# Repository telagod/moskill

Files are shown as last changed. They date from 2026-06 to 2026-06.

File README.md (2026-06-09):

<p align="center">
  MosKill Logo
</p>

<h1 align="center">MosKill</h1>
<p align="center">
  <strong>Smart Mosquito Swatter with BLE, Kill Counting & Statistics</strong><br/>
  <em>ESP32-C3 Firmware + KiCad PCB + UniApp Cross-Platform Client</em>
</p>

<p align="center">
  
  
  
  
  
  
  
</p>

---

## System Architecture

<p align="center">
  System Architecture
</p>

## Features

- **Kill Detection** — Current pulse analysis, 4-class classification (S Fruit Fly / M Mosquito / L House Fly / XL Moth)
- **Statistics Engine** — Total kills, streak records, hourly heatmap, size distribution, efficiency scoring
- **Environment Correlation** — AHT20 temp/humidity sensing, mosquito activity vs. environment cross-analysis
- **BLE 5.0** — Real-time kill notifications, stats read, device config, OTA firmware update
- **UI Feedback** — WS2812B color-coded kill effects, streak rainbow animation, buzzer sound FX
- **Power Management** — 18650 Li-ion USB-C charging, 5-min auto deep sleep (5uA)
- **Cross-Platform App** — WeChat Mini Program / Android / iOS / H5, i18n (zh/en), dev mode
- **Fully AI-Designed** — From empty directory to manufacturable Gerber, zero human intervention

## PCB Design

30 x 100 mm narrow strip designed to fit inside a mosquito swatter handle. 91 components, dual-layer with full GND pour.

<p align="center">
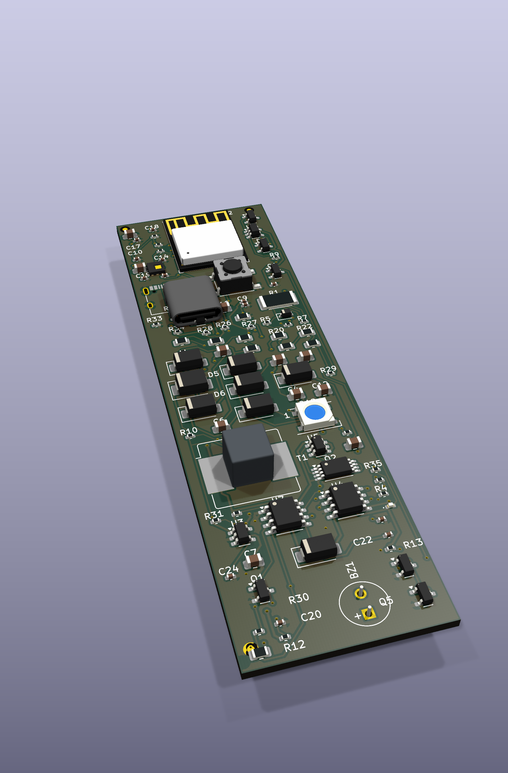
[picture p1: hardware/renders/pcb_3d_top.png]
PCB 3D Top
  
  &nbsp;&nbsp;&nbsp;&nbsp;
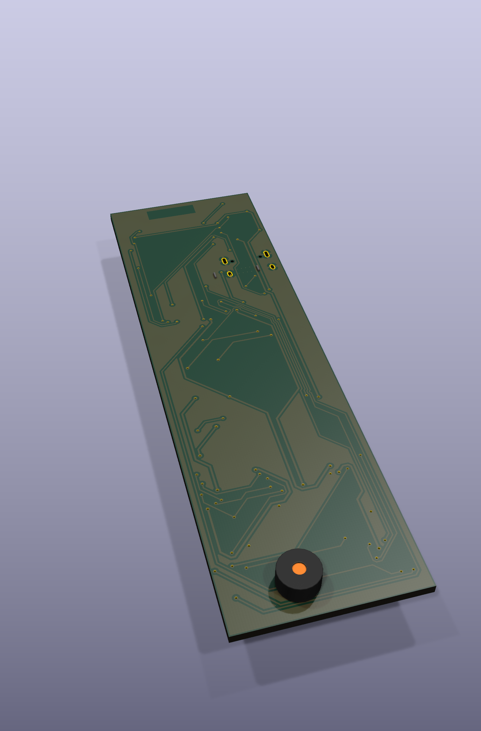
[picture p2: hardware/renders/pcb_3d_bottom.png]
PCB 3D Bottom
  
  &nbsp;&nbsp;&nbsp;&nbsp;
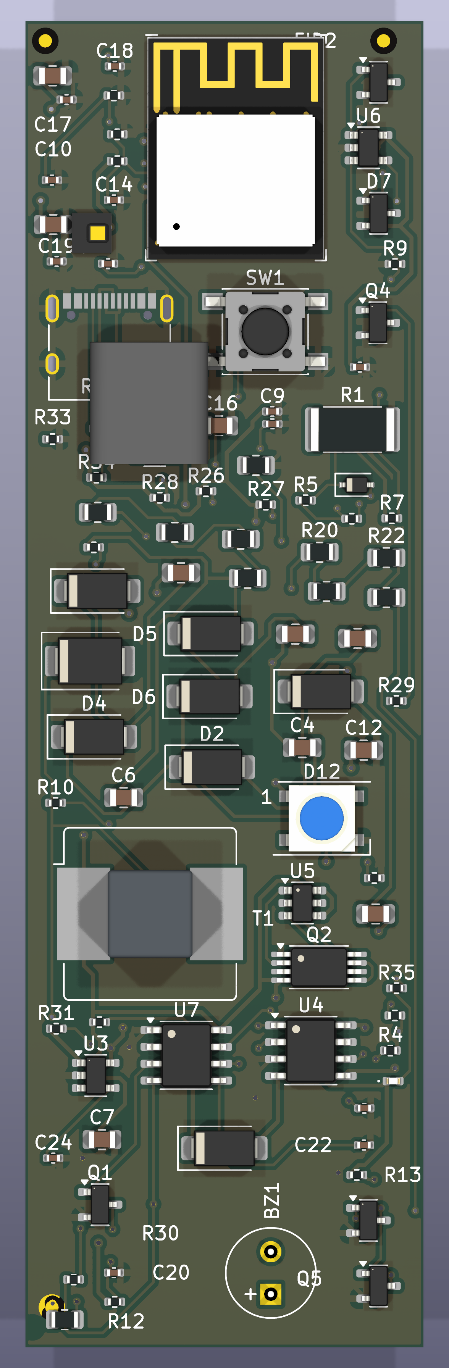
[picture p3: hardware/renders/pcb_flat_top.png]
PCB Flat Top
  
  &nbsp;&nbsp;&nbsp;&nbsp;
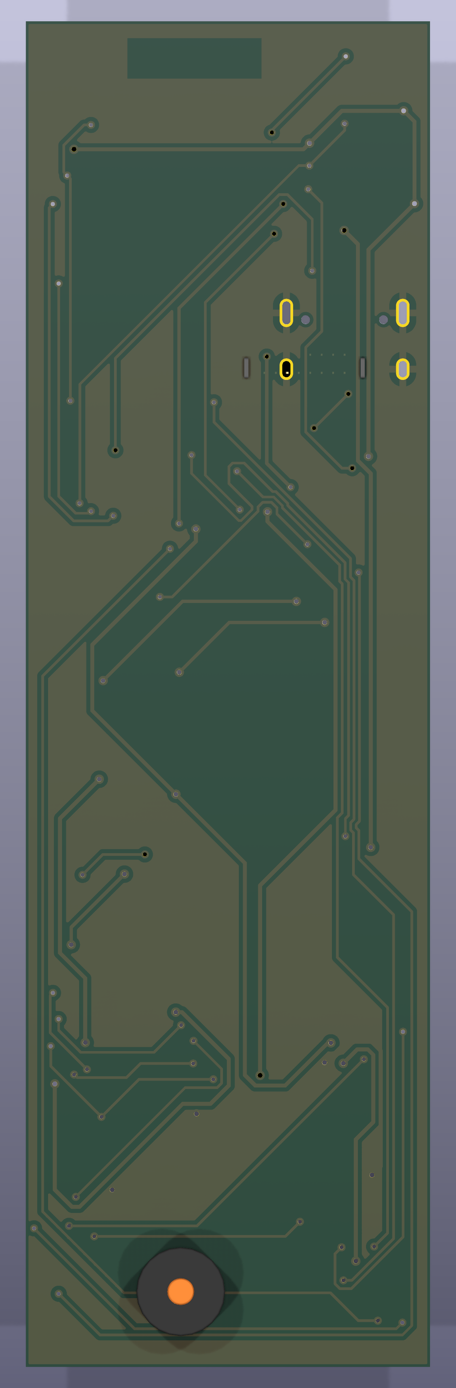
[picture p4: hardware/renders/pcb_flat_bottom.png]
PCB Flat Bottom
  
</p>
<p align="center"><em>Left to right: 3D Top, 3D Bottom, Flat Top, Flat Bottom</em></p>

## Hardware

| Component | Part | Function |
|---|---|---|
| MCU | ESP32-C3-MINI-1 | RISC-V 160MHz, BLE 5.0, 4MB Flash |
| HV Boost | NE555 + AO3400 + EE13 Transformer (10:200) | 3.7V -> ~2000V DC |
| HV Multiplier | 3-stage Cockcroft-Walton (UF4007 + 1nF/2kV) | Voltage tripler |
| Current Sense | 0.1ohm + LMV358 (Gain=20) + BAT43 Peak Det | Kill waveform capture |
| Env Sensor | AHT20 (I2C) | Temp +/-0.3C / Humidity +/-2%RH |
| Power | 18650 + TP4056 + ME6211 LDO | USB-C charging, 3.3V regulated |
| Battery Protect | DW01A + FS8205A | Over-charge/discharge/current protection |
| LED | WS2812B | RGB status + kill effects |
| Buzzer | KCG0601 Passive Piezo | Kill sound FX + streak rising tone |

> Full schematic: [`hardware/kicad/moskill.kicad_sch`](hardware/kicad/moskill.kicad_sch) | BOM: [`hardware/bom/BOM.csv`](hardware/bom/BOM.csv) | Gerber: [`hardware/kicad/moskill-gerbers.zip`](hardware/kicad/moskill-gerbers.zip)

## Project Structure

```
moskill/
├── firmware/                        # ESP-IDF v5.4 firmware (938KB binary)
│   ├── main/                        # Entry point, 6 FreeRTOS tasks
│   └── components/
│       ├── kill_detector/           # 4-state kill detection FSM
│       ├── stats_engine/            # Statistics + NVS sharded storage
│       ├── ble_service/             # BLE GATT server + OTA handler
│       ├── env_sensor/              # AHT20 I2C driver (thread-safe)
│       ├── power_mgmt/             # Battery curve, HV control, deep sleep
│       └── hv_driver/              # WS2812B RMT driver
├── hardware/
│   ├── kicad/                       # KiCad 9 schematic + PCB (30x100mm)
│   ├── bom/BOM.csv                  # 48 line items, ~¥24.48
│   └── renders/                     # 3D and flat PCB renders
├── app/                             # UniApp cross-platform client
│   └── src/
│       ├── pages/                   # 7 pages (dashboard, stats, rank, control, ota, ...)
│       ├── components/MkIcon.vue    # SVG icon component (38 icons)
│       ├── utils/
│       │   ├── ble.js               # BLE communication layer (128-bit UUIDs)
│       │   ├── icons.js             # SVG icon definitions
│       │   ├── i18n.js              # Chinese/English auto-switch
│       │   └── mock.js              # Dev mode mock data generator
│       └── store/index.js           # Vuex state management
├── protocol/ble_protocol.md         # BLE GATT protocol specification
├── tools/ble_debug/                 # Python BLE debug tool (bleak + rich)
└── docs/DESIGN.md                   # Full system design document
```

## Build Firmware

```bash
# Install ESP-IDF v5.4+
# https://docs.espressif.com/projects/esp-idf/en/latest/esp32c3/get-started/

cd firmware
idf.py set-target esp32c3
idf.py build                         # -> build/moskill.bin (938KB)
idf.py -p /dev/ttyUSB0 flash monitor
```

## Build App

```bash
cd app
npm install
npx uni build                        # H5 build
npx uni build -p mp-weixin           # WeChat Mini Program
npx uni dev:h5                       # H5 dev server

# Dev mode: no device needed, uses mock data for UI development
```

## Kill Detection Pipeline

```
ADC 1kHz sampling -> Threshold trigger -> Sustain check (>=5ms)
    -> Peak capture -> Envelope match -> Classification -> Stats update
    -> BLE notify -> LED + Buzzer feedback

Classification by peak ADC:
  S  (< 800)    Fruit Fly
  M  (800-2000) Mosquito
  L  (2000-3200) House Fly
  XL (> 3200)   Moth / Beetle
```

## BLE Protocol

128-bit custom UUIDs (base `e3a1XXXX-f5e8-4c8a-9b3d-2c1f7b8a6d50`), packed wire format for efficiency.

| Service | UUID Short | Description |
|---|---|---|
| MosKill Main | `0x1B00` | Kill count (notify), session/lifetime stats, kill log, environment |
| Config | `0x1B11` | Sensitivity, LED, buzzer, streak effects + time sync |
| OTA | `0x1B21` | Firmware update (start/write/verify/abort with CRC32) |
| Battery | `0x180F` | Standard Battery Service |

> Full protocol spec: [`protocol/ble_protocol.md`](protocol/ble_protocol.md)

## BLE Debug Tool

```bash
cd tools/ble_debug
pip install -r requirements.txt

python moskill_ble.py scan                          # Scan devices
python moskill_ble.py stats <ADDR>                  # Read statistics
python moskill_ble.py monitor <ADDR>                # Real-time kill monitor
python moskill_ble.py config <ADDR> -s 2 -b 3      # Set sensitivity/buzzer
python moskill_ble.py ota <ADDR> firmware.bin       # BLE OTA update
```

## License

MIT

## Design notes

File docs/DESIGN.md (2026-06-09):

# MosKill - Smart Electric Mosquito Swatter

## System Overview

ESP32-C3 based smart mosquito swatter with BLE connectivity, real-time kill detection via current pulse analysis, and comprehensive kill statistics including waveform classification, environmental correlation, and efficiency scoring.

```
┌─────────────────────────────────────────────────────┐
│                   MosKill System                    │
│                                                     │
│  ┌──────────┐   ┌──────────┐   ┌───────────────┐   │
│  │ HV Grid  │──▶│ Current  │──▶│   ESP32-C3    │   │
│  │ 3-layer  │   │ Sensing  │   │               │   │
│  └──────────┘   └──────────┘   │  ┌─────────┐  │   │
│                                │  │Kill Det. │  │   │
│  ┌──────────┐                  │  ├─────────┤  │   │
│  │ Boost    │◀─────────────────│  │Stats Eng│  │   │
│  │ Converter│   Control        │  ├─────────┤  │   │
│  └──────────┘                  │  │BLE Stack│  │   │
│                                │  ├─────────┤  │   │
│  ┌──────────┐                  │  │Power Mgr│  │   │
│  │ AHT20    │─────────────────▶│  ├─────────┤  │   │
│  │Temp/Humi │   I2C            │  │Env Sense│  │   │
│  └──────────┘                  │  └─────────┘  │   │
│                                └───────────────┘   │
│  ┌──────────┐   ┌──────────┐                       │
│  │ Li-ion   │──▶│ LDO 3.3V │──▶ System Power       │
│  │ 18650    │   │ ME6211   │                       │
│  └──────────┘   └──────────┘                       │
└─────────────────────────────────────────────────────┘
```

## 1. Hardware Architecture

### 1.1 MCU - ESP32-C3-MINI-1

| Parameter | Value |
|---|---|
| Core | RISC-V 32-bit, 160MHz |
| Flash | 4MB |
| SRAM | 400KB |
| BLE | 5.0 |
| ADC | 12-bit SAR, 6 channels |
| GPIO | 22 pins |
| Deep Sleep | 5μA |
| Package | ESP32-C3-MINI-1 module |

#### Pin Assignment

| Pin | Function | Description |
|-----|---|---|
| GPIO0 | ADC_CH0 | Current sense input (via analog frontend) |
| GPIO1 | ADC_CH1 | Battery voltage divider |
| GPIO2 | BOOT | Boot mode (active low) |
| GPIO3 | ADC_CH3 | Env sensor aux (optional) |
| GPIO4 | I2C_SDA | AHT20 data |
| GPIO5 | I2C_SCL | AHT20 clock |
| GPIO6 | HV_EN | High voltage boost enable |
| GPIO7 | LED_STATUS | Status LED (RGB WS2812B) |
| GPIO8 | BUZZER | Piezo buzzer PWM |
| GPIO9 | BUTTON | Main button (active low, internal pull-up) |
| GPIO10 | CHG_STAT | TP4056 charge status |
| GPIO18 | USB_D- | USB-C data |
| GPIO19 | USB_D+ | USB-C data |
| GPIO20 | UART_RX | Debug UART |
| GPIO21 | UART_TX | Debug UART |

### 1.2 High Voltage System

#### Boost Converter (Battery → HV)

```
Li-ion 3.7V ──▶ Oscillator + Transformer ──▶ Voltage Multiplier ──▶ ~2000V DC
                     │                              │
                  GPIO6 EN                    Current Sense
                                                    │
                                              To Analog Frontend
```

**Oscillator**: NE555 astable driving MOSFET gate
- R_A = 4.7kΩ, R_B = 10kΩ, C_t = 10nF
- f = 1.44 / ((R_A + 2×R_B) × C_t) = 1.44 / ((4.7k + 2×10k) × 10nF) = **5.83kHz**
- Duty cycle = (R_A + R_B) / (R_A + 2×R_B) = 14.7k / 24.7k = **59.5%**

**MOSFET**: AO3400 (N-ch, Vds=30V, Rds_on=40mΩ, Id=5.7A, SOT-23)
- RC snubber across drain-source: **100Ω + 1nF** (suppresses ringing)
- TVS across drain-source: **SMBJ24A** (24V standoff, 38.9V clamp, flyback protection)

**Transformer**: EE13 or EE16 core, **10:200 winding ratio (1:20 effective)**
- 10 primary turns: inductance ~200μH
- Peak primary current: I = V × t_on / L = 3.7V × 100μs / 200μH = **1.85A** (safe for AO3400)
- 200 secondary turns: V_sec_peak = V_in × N_s/N_p = 3.7 × 20 = **~740V peak** at 3.7V input

**Voltage Multiplier**: Cockcroft-Walton 3-stage
- C: 1nF 2kV rated (C0G dielectric)
- D: **UF4007** (fast recovery, trr=75ns, 1kV, 1A) — standard 1N4007 too slow for 5.8kHz switching
- No-load output: 6 × 740V = 4440V theoretical × 0.7 efficiency ≈ **3100V**
- Loaded output (grid + insect): **~2000V DC** target achieved
- Design margin: Vout adjustable via duty cycle / frequency trim

**Grid**: 3-layer structure
- Outer layers: Ground reference
- Inner layer: High voltage
- Spacing: 3-4mm

#### Current Sensing Analog Frontend

```
HV Return ──┤R_sense├──▶ GND
                │
                ▼
         ┌──────────────┐
         │  R_sense      │  0.1Ω 2W (gives 100mV at 1A, manageable range)
         │  voltage drop │
         └──────┬───────┘
                │
         ┌──────▼───────┐
         │ Series Limit  │  1kΩ resistor BEFORE clamp (limits inrush to clamp diodes)
         │ Resistor      │
         └──────┬───────┘
                │
         ┌──────▼───────┐
         │ Clamping      │  BAT54S Schottky clamp to 0-3.3V
         │ Protection    │
         └──────┬───────┘
                │
         ┌──────▼───────┐
         │ Backup Zener  │  BZX84C3V3 (3.3V Zener, SOT-23) — secondary hard clamp
         └──────┬───────┘
                │
         ┌──────▼───────┐
         │ Op-Amp Stage  │  LMV358 (rail-to-rail, 3.3V)
         │ Gain = 20     │  Non-inverting: Rf=19kΩ, Rg=1kΩ
         │ BW filter     │  RC LPF at 10kHz (anti-alias)
         └──────┬───────┘
                │
         ┌──────▼───────┐
         │ Peak Detector │  BAT43 Schottky (Vf≈0.2V, preserves small signals)
         │ + Envelope    │  + RC hold: 1μF × 100kΩ = τ = 100ms
         └──────┬───────┘
                │
                ▼
           GPIO0 (ADC)     12-bit, sampled at 1kHz during active mode
```

**Design Notes:**
- R_sense = 0.1Ω 2W: produces 10-100mV at typical kill currents (100mA-1A peak)
- 1kΩ series resistor before BAT54S clamp limits fault current into protection diodes
- BZX84C3V3 Zener backup provides hard 3.3V clamp if Schottky clamp fails
- LMV358 gain of 20x (Rf=19kΩ, Rg=1kΩ) maps 0-165mV to 0-3.3V, linear up to 1.65A
- RC filter (R=1.5kΩ, C=10nF → fc ≈ 10.6kHz) for anti-aliasing
- Peak detector uses BAT43 Schottky (low Vf ≈ 0.2V) to preserve small signals
- Peak detector with 1μF + 100kΩ gives τ = 100ms — fast enough for consecutive kills

### 1.3 Power System

#### Battery
- Cell: 18650 Li-ion, 2600mAh
- Nominal: 3.7V (range 3.0V-4.2V)
- Protection: DW01A + FS8205A (overcurrent, overdischarge, overcharge)

#### Charging
- IC: TP4056 with DW01A
- Input: USB-C (5V) with **SS34 Schottky** in series for VBUS reverse protection
- USB ESD protection: **USBLC6-2SC6** on D+/D- lines
- Input capacitor: **4.7μF** (per TP4056 datasheet, 100nF insufficient for USB cable inductance)
- TEMP pin: connected through **10kΩ to VCC** (NOT to GND — GND disables charging)
- Charge current: 500mA (R_prog = 2kΩ)
- Status: CHRG pin → GPIO10

#### LDO Regulator
- IC: ME6211C33 (3.3V, 500mA, low Iq)
- Decoupling: 10μF + 100nF at output
- Enable: Always on (tied to battery via switch)

#### Battery Monitoring
- Voltage divider: **10kΩ / 10kΩ** → GPIO1 (ADC), with **100nF** filter cap at midpoint
  - Lower impedance reduces ADC noise and leakage current errors
  - Quiescent draw: ~0.2mA (acceptable vs. 100kΩ divider's noise issues)
- Reading: V_bat = ADC_reading × 2 × 3.3 / 4095
- Calibrated curve for SoC estimation

### 1.4 Environmental Sensor

- IC: AHT20 (I2C, 0x38)
- Temperature: -40°C to +85°C, ±0.3°C
- Humidity: 0-100% RH, ±2%
- Power: 2.2-5.5V, typ 23μA
- Sample rate: Every 30 seconds (low duty)

### 1.5 User Interface

#### Status LED (WS2812B)
| State | Color | Pattern |
|---|---|---|
| Idle | Off | - |
| Armed (HV on) | Red | Steady |
| Kill detected | Green | Flash 200ms |
| Multi-kill streak | Rainbow | Chase 500ms |
| BLE connected | Blue | Breathe |
| Charging | Orange | Pulse |
| Low battery | Red | Blink slow |

#### Buzzer (Passive piezo)
- Kill confirm: 2kHz, 50ms
- Streak (3+): Rising tone
- Low battery: 1kHz, 3× beep
- BLE connect: 2-tone chime

#### Button
- Short press: Toggle HV on/off
- Long press (3s): BLE advertising toggle
- Double press: Read stats via buzzer pattern

### 1.6 PCB Specifications

| Parameter | Value |
|---|---|
| Dimensions | 35mm × 60mm (fits in swatter handle) |
| Layers | 2 |
| Copper | 1oz outer |
| Finish | HASL lead-free |
| Min trace | 0.2mm (8mil) |
| Min drill | 0.3mm |
| HV clearance | ≥ 4mm between HV traces and LV |
| Substrate | FR-4 1.6mm |

**Layout Zones:**
```
┌─────────────────────────────┐
│  USB-C    │   ESP32-C3      │
│  TP4056   │   Module        │
│  Charging │                 │
├───────────┤   BLE Antenna   │
│  Battery  │   Keep-out      │
│  Mgmt     │   Zone          │
├───────────┼─────────────────┤
│  Analog Frontend            │
│  (Ground guarded)           │
├─────────────────────────────┤
│  HV Section                 │
│  (Isolated, 4mm clearance)  │
│  NE555 + MOSFET + Xformer   │
│  Voltage Multiplier         │
│  Routing slots between zones│
│  Conformal coating required │
└─────────────────────────────┘
```

## 2. Firmware Architecture

### 2.1 RTOS Task Structure (ESP-IDF / FreeRTOS)

```
┌─────────────────────────────────────────────┐
│              FreeRTOS Tasks                  │
│                                              │
│  ┌────────────┐  Priority: 5 (Highest)       │
│  │ kill_detect │  Core 0, 4KB stack           │
│  │ _task       │  1kHz ADC sampling           │
│  └─────┬──────┘  → kill event queue           │
│        │                                      │
│  ┌─────▼──────┐  Priority: 4                  │
│  │ stats_task  │  Core 0, 8KB stack            │
│  │             │  Process kill events          │
│  └─────┬──────┘  → update stats, flash write  │
│        │                                      │
│  ┌─────▼──────┐  Priority: 3                  │
│  │ ble_task    │  Core 0, 6KB stack            │
│  │             │  GATT server, notifications   │
│  └────────────┘                               │
│                                               │
│  ┌────────────┐  Priority: 2                  │
│  │ env_task    │  Core 0, 2KB stack            │
│  │             │  AHT20 polling every 30s      │
│  └────────────┘                               │
│                                               │
│  ┌────────────┐  Priority: 1                  │
│  │ ui_task     │  Core 0, 2KB stack            │
│  │             │  LED + buzzer + button        │
│  └────────────┘                               │
│                                               │
│  ┌────────────┐  Priority: 0 (Lowest)         │
│  │ power_task  │  Core 0, 2KB stack            │
│  │             │  Battery monitoring, sleep    │
│  └────────────┘                               │
└─────────────────────────────────────────────┘
```

### 2.2 Kill Detection Algorithm

```
State Machine:
                    ┌──────────┐
            ┌──────▶│  IDLE    │◀─────────────┐
            │       └────┬─────┘              │
            │            │ ADC > threshold_low │
            │            ▼                     │
            │       ┌──────────┐              │
            │       │ TRIGGERED│              │
            │       └────┬─────┘              │
            │            │ sustain > 5ms       │
            │            ▼                     │
            │       ┌──────────┐   timeout    │
            │       │CONFIRMING├──────────────┘
            │       └────┬─────┘
            │            │ peak captured +
            │            │ envelope matches
            │            ▼
            │       ┌──────────┐
            └───────┤KILL_EVENT│
                    │ → queue  │
                    └──────────┘

Parameters:
- threshold_low:  200 (ADC counts, ~160mV → ~16mV at sense resistor)
- threshold_high: 3800 (ADC counts, clipping protection)
- min_sustain:    5ms (debounce, reject static/EMI)
- max_duration:   500ms (reject continuous shorts)
- cooldown:       200ms (between consecutive kills)
- envelope_match: rise < 2ms, hold 5-50ms, decay < 100ms
```

### 2.3 Kill Classification

Based on discharge waveform characteristics:

| Class | Peak ADC | Duration | Energy Proxy | Likely Target |
|---|---|---|--- |---|
| S (Small) | 200-800 | 5-15ms | Low | Fruit fly, gnat |
| M (Medium) | 800-2000 | 10-30ms | Medium | Mosquito |
| L (Large) | 2000-3200 | 20-80ms | High | House fly, moth |
| XL (Extra) | 3200+ | 50-200ms | Very High | Large moth, beetle |

Energy proxy = Σ(ADC_sample²) over event duration (proportional to I²t)

### 2.4 Statistics Engine

#### Data Structures (NVS Storage)

```c
// Per-session stats (RAM, flushed to NVS on session end)
typedef struct {
    uint32_t session_id;
    uint32_t start_time;        // epoch seconds
    uint32_t duration_sec;
    uint16_t kills_total;
    uint16_t kills_by_class[4]; // S, M, L, XL
    uint16_t max_streak;
    uint16_t current_streak;
    float    avg_temp;
    float    avg_humidity;
    uint32_t energy_total;      // Σ energy proxy
    uint16_t hv_on_time_sec;
    uint16_t swings_estimated;  // from accelerometer-free proxy (HV on/off cycles)
} session_stats_t;

// Lifetime aggregates (NVS, updated on session end)
typedef struct {
    uint32_t total_kills;
    uint32_t kills_by_class[4];
    uint32_t total_sessions;
    uint32_t total_active_sec;
    uint32_t best_streak;
    uint32_t best_session_kills;
    float    kill_rate_per_hour; // rolling average
    uint8_t  hourly_histogram[24];  // kills per hour-of-day
    uint8_t  daily_histogram[7];    // kills per day-of-week
} lifetime_stats_t;

// Kill event log (circular buffer in NVS, last 256 kills)
typedef struct {
    uint32_t timestamp;
    uint8_t  kill_class;        // S=0, M=1, L=2, XL=3
    uint16_t peak_adc;
    uint16_t duration_ms;
    uint32_t energy_proxy;
    int8_t   temperature;       // °C, rounded
    uint8_t  humidity;          // %RH, rounded
} kill_event_t;
```

#### Derived Metrics (computed on read, not stored)

- **Kill Rate**: kills / HV-on-hours
- **Efficiency Score**: kills / (HV-on-time × energy) — higher = more efficient swatter
- **Peak Hour**: hour-of-day with most kills historically
- **Mosquito Pressure Index**: kills/hour normalized by temp/humidity (higher temp+humidity = more mosquitoes expected, so fewer kills ≠ fewer mosquitoes)
- **Streak Record**: longest consecutive kills within 10s window
- **Size Distribution**: pie chart data of S/M/L/XL

## 3. BLE Protocol

See [protocol/ble_protocol.md](../protocol/ble_protocol.md) for full specification.

### GATT Service Summary

| Service | UUID | Description |
|---|---|---|
| MosKill Service | `0x1B00` | Primary service |
| Kill Count | `0x1B01` | Total kills (notify on change) |
| Session Stats | `0x1B02` | Current session (read) |
| Lifetime Stats | `0x1B03` | All-time stats (read) |
| Kill Log | `0x1B04` | Recent kills (read, paginated) |
| Environment | `0x1B05` | Temp + humidity (notify) |
| Battery | `0x180F` | Standard BAS |
| Device Info | `0x180A` | Standard DIS |
| Config | `0x1B10` | Sensitivity, LED, buzzer settings |
| Time Sync | `0x1B11` | Set RTC from phone |
| OTA | `0x1B20` | Firmware update |

## 4. Bill of Materials (Key Components)

| # | Component | Part | Qty | Est. Cost (¥) |
|---|---|---|-----|---|
| 1 | MCU Module | ESP32-C3-MINI-1 | 1 | 9.00 |
| 2 | Temp/Humidity | AHT20 | 1 | 2.50 |
| 3 | LDO | ME6211C33M5G | 1 | 0.30 |
| 4 | Charge IC | TP4056 | 1 | 0.40 |
| 5 | Battery Protect | DW01A + FS8205A | 1+1 | 0.50 |
| 6 | Op-Amp | LMV358 | 1 | 0.80 |
| 7 | HV MOSFET | AO3400 (N-ch, 30V, 40mΩ) | 1 | 0.35 |
| 8 | Timer | NE555 | 1 | 0.30 |
| 9 | HV Transformer | EE13/EE16 10:200 | 1 | 2.00 |
| 10 | HV Diodes | UF4007 (fast recovery) | 6 | 0.60 |
| 11 | HV Caps | 1nF 2kV | 6 | 0.60 |
| 12 | Sense Resistor | 0.1Ω 2W | 1 | 0.15 |
| 13 | Clamp Diode | BAT54S | 1 | 0.20 |
| 14 | Peak Det. Diode | BAT43 (Schottky) | 1 | 0.15 |
| 15 | Backup Zener | BZX84C3V3 | 1 | 0.10 |
| 16 | TVS Diode | SMBJ24A | 1 | 0.50 |
| 17 | RGB LED | WS2812B | 1 | 0.30 |
| 18 | Buzzer | Passive piezo | 1 | 0.50 |
| 19 | USB-C Connector | 16-pin | 1 | 0.50 |
| 20 | USB Reverse Prot. | SS34 Schottky | 1 | 0.30 |
| 21 | USB ESD Prot. | USBLC6-2SC6 | 1 | 0.50 |
| 22 | Discharge MOSFET | 2N7002 (N-ch) | 1 | 0.10 |
| 23 | Button | 6×6mm tactile | 1 | 0.10 |
| 24 | HV Bleed Resistors | 1MΩ 0805 200V | 10 | 0.20 |
| 25 | Snubber R | 100Ω 0402 | 1 | 0.01 |
| 26 | Snubber C | 1nF 0402 | 1 | 0.01 |
| 27 | Discharge R | 100Ω 0805 | 1 | 0.01 |
| 28 | Passives | R, C assorted | ~30 | 1.00 |
| 29 | PCB | 2-layer 35×60mm | 1 | 3.00 |
| | **Total** | | | **~¥24.48** |

(Battery 18650 and grid/handle not included — mechanical parts)

## 5. Safety Considerations

- HV section isolated with **4mm clearance** on PCB
- **PCB routing slots** between HV and LV zones to increase creepage distance
- **Conformal coating** required on HV section (silicone or acrylic, IPC-CC-830)
- Grid auto-discharge via bleed resistor chain (see below)
- Overcurrent protection via sense resistor + software cutoff
- **USB ESD protection**: USBLC6-2SC6 on D+/D- lines
- **USB reverse protection**: SS34 Schottky in series with VBUS
- Battery protection IC prevents overcurrent/undervoltage/overvoltage
- Transformer limited by oscillator duty cycle — cannot exceed ~3100V no-load
- Ground layer pour on LV section; separate ground pour for analog frontend

### 5.1 Safety Circuits

#### Hardware Watchdog on HV_EN

External RC timeout circuit prevents indefinite HV operation if MCU crashes:

```
GPIO6 (HV_EN) ──── 100kΩ ────┬──── HV Enable (gate of enable MOSFET)
                              │
                            10μF
                              │
                             GND
```

- MCU must output **PWM** (not static HIGH) to keep HV armed
- RC time constant: τ = 100kΩ × 10μF = **1 second**
- If MCU crashes (GPIO goes static or Hi-Z), cap discharges in ~1s and HV turns off automatically
- PWM frequency: ~100Hz minimum to maintain cap charge above threshold

#### Grid Rapid Discharge

When HV is disabled, residual grid charge must be drained quickly:

```
HV Grid ──── 100Ω ────┬──── Drain of 2N7002
                       │
                      GND (via 2N7002 source)

2N7002 Gate ──── Inverted HV_EN (via NPN inverter or spare NE555 section)
```

- **2N7002** N-MOSFET (Vds=60V, Id=115mA, SOT-23) shorts grid through 100Ω when HV_EN is LOW
- Discharge time constant depends on grid capacitance (~10-50pF): effectively instant
- 100Ω limits peak discharge current to protect MOSFET and grid conductors

#### Bleed Resistor Chain

- **10× 1MΩ** resistors in series (each 0805 package, 200V rated per resistor)
- Total: 10MΩ at 2kV — each resistor sees only 200V (within 0805 rating)
- Provides passive discharge path: τ = 10MΩ × ~30pF (grid) ≈ 0.3ms
- Serves as backup to active discharge circuit

#### HV Clearance Requirements

| Parameter | Requirement |
|---|---|
| PCB trace clearance (HV to LV) | ≥ 4mm |
| Routing slots | Required between HV and LV zones |
| Conformal coating | Silicone or acrylic per IPC-CC-830 |
| Component placement | No LV components within 4mm of HV traces |
| Grid wire insulation | Silicone sleeving on HV connections to PCB |

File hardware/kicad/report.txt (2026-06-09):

已将 ESP32-C3-L 从 U1A 更新至 U1A1。
已将 ESP32-C3-R 从 U1B 更新至 U1B1。
批注完成。
批注完成。

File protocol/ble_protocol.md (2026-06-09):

# MosKill BLE Protocol Specification v1.0

## Overview

BLE 5.0 GATT-based protocol for MosKill smart mosquito swatter.
Device acts as GATT Server (Peripheral). Phone app acts as GATT Client (Central).

## Advertising

| Parameter | Value |
|---|---|
| Name | `MosKill-XXXX` (last 4 of MAC) |
| Interval | 200ms (fast) / 1000ms (slow, after 30s) |
| TX Power | 0 dBm |
| Flags | LE General Discoverable + BR/EDR Not Supported |
| Service UUID | `0x1B00` in Complete List of 16-bit UUIDs |
| Manufacturer Data | `[0xFF, 0xFF, kill_count_lo, kill_count_hi, battery_pct, flags]` |

**Flags byte:**
| Bit | Meaning |
|-----|---|
| 0 | HV armed |
| 1 | Charging |
| 2 | Low battery |
| 3-7 | Reserved |

## GATT Services & Characteristics

### 1. MosKill Service (`0x1B00`)

#### 1.1 Kill Count (`0x1B01`)
| Property | Value |
|---|---|
| Properties | Read, Notify |
| Format | uint32 (little-endian) |
| Description | Total kills in current session |
| CCCD | `0x2902` (enable notifications) |

Notification sent on each kill event. Client subscribes to get real-time kill feed.

#### 1.2 Session Stats (`0x1B02`)
| Property | Value |
|---|---|
| Properties | Read |
| Format | Custom struct (see below) |
| Max length | 40 bytes |

```
Offset  Size  Field
0       4     session_id (uint32)
4       4     start_time (uint32, epoch)
8       4     duration_sec (uint32)
12      2     kills_total (uint16)
14      2     kills_S (uint16)
16      2     kills_M (uint16)
18      2     kills_L (uint16)
20      2     kills_XL (uint16)
22      2     max_streak (uint16)
24      4     energy_total (uint32)
28      2     avg_temp_x10 (int16, °C×10)
30      2     avg_humidity_x10 (uint16, %×10)
32      2     hv_on_time_sec (uint16)
34      2     efficiency_x100 (uint16, score×100)
36      4     reserved
```

#### 1.3 Lifetime Stats (`0x1B03`)
| Property | Value |
|---|---|
| Properties | Read |
| Format | Custom struct |
| Max length | 80 bytes |

```
Offset  Size  Field
0       4     total_kills (uint32)
4       4     kills_S (uint32)
8       4     kills_M (uint32)
12      4     kills_L (uint32)
16      4     kills_XL (uint32)
20      4     total_sessions (uint32)
24      4     total_active_sec (uint32)
28      4     best_streak (uint32)
32      4     best_session_kills (uint32)
36      4     kill_rate_x100 (uint32, per-hour×100)
40      24    hourly_histogram[24] (uint8×24)
64      7     daily_histogram[7] (uint8×7, Mon=0)
71      1     padding
72      4     first_use_time (uint32, epoch)
76      4     reserved
```

#### 1.4 Kill Log (`0x1B04`)
| Property | Value |
|---|---|
| Properties | Read |
| Format | Custom struct, paginated |
| Max length | 200 bytes per read |

**Read with offset**: Client writes page number (uint8) to trigger read.
Each page = 10 kill events, newest first.

```
Per-event (16 bytes):
Offset  Size  Field
0       4     timestamp (uint32, epoch)
4       1     kill_class (uint8: 0=S, 1=M, 2=L, 3=XL)
5       2     peak_adc (uint16)
7       2     duration_ms (uint16)
9       4     energy_proxy (uint32)
13      1     temperature (int8, °C)
14      1     humidity (uint8, %)
15      1     reserved

Page header (4 bytes):
0       1     page_number (uint8)
1       1     total_pages (uint8)
2       2     events_in_page (uint16)

Total per page: 4 + 10×16 = 164 bytes
```

#### 1.5 Environment (`0x1B05`)
| Property | Value |
|---|---|
| Properties | Read, Notify |
| Format | 4 bytes |
| Notify interval | 30 seconds |

```
Offset  Size  Field
0       2     temperature_x10 (int16, °C×10)
2       2     humidity_x10 (uint16, %RH×10)
```

### 2. Battery Service (`0x180F`) — Standard BAS

#### 2.1 Battery Level (`0x2A19`)
| Property | Value |
|---|---|
| Properties | Read, Notify |
| Format | uint8 (0-100%) |
| Notify | On 5% change |

### 3. Device Information Service (`0x180A`) — Standard DIS

| Characteristic | UUID | Value |
|---|---|---|
| Manufacturer | `0x2A29` | `"MosKill"` |
| Model Number | `0x2A24` | `"MK-01"` |
| Firmware Rev | `0x2A26` | `"1.0.0"` |
| Hardware Rev | `0x2A27` | `"1.0"` |
| Serial Number| `0x2A25` | MAC-derived |

### 4. Configuration Service (`0x1B10`)

#### 4.1 Device Config (`0x1B11`)
| Property | Value |
|---|---|
| Properties | Read, Write |
| Format | 8 bytes |

```
Offset  Size  Field
0       1     kill_sensitivity (uint8: 0=low, 1=med, 2=high)
1       1     led_brightness (uint8: 0-255)
2       1     buzzer_volume (uint8: 0=off, 1=low, 2=med, 3=high)
3       1     buzzer_on_kill (uint8: 0=off, 1=on)
4       1     led_on_kill (uint8: 0=off, 1=on)
5       1     streak_effects (uint8: 0=off, 1=on)
6       2     reserved
```

#### 4.2 Time Sync (`0x1B12`)
| Property | Value |
|---|---|
| Properties | Write |
| Format | 4 bytes |

Write uint32 epoch seconds to sync internal RTC.

### 5. OTA Service (`0x1B20`)

#### 5.1 OTA Control (`0x1B21`)
| Property | Value |
|---|---|
| Properties | Write, Notify |
| Format | Variable |

| Command (byte 0) | Payload | Description |
|---|---|---|
| `0x01` | `[total_size: uint32]` | Start OTA, send firmware size |
| `0x02` | `[offset: uint32, data: bytes]` | Write chunk (max 240 bytes) |
| `0x03` | `[crc32: uint32]` | Verify and apply |
| `0x04` | - | Abort OTA |

Notification responses:
| Status | Meaning |
|---|---|
| `0x00` | OK / ACK |
| `0x01` | CRC error |
| `0x02` | Flash error |
| `0x03` | Size mismatch |
| `0xFF` | Abort |

## Connection Parameters

| Parameter | Value |
|---|---|
| Min Interval | 15ms |
| Max Interval | 30ms (active) / 500ms (idle) |
| Slave Latency | 0 (active) / 4 (idle) |
| Timeout | 4000ms |
| MTU | Request 247 (for kill log pages) |

## Security

| Parameter | Value |
|---|---|
| Pairing | Just Works (no MITM needed for a swatter) |
| Bonding | Yes (remember paired devices) |
| Encryption | AES-CCM (BLE 4.2+ standard) |
| Max bonds | 4 devices |

## Data Flow

```
Kill Event:
  Grid discharge → ADC → kill_detect_task → kill_queue
       → stats_task (update session/lifetime, write NVS)
       → ble_task (notify kill count char 0x1B01)
       → ui_task (LED flash + buzzer beep)

Phone Connection:
  Phone → scan → connect → discover services
       → subscribe to 0x1B01 (kill count)
       → subscribe to 0x1B05 (environment)
       → subscribe to 0x2A19 (battery)
       → read 0x1B02 (session stats)
       → read 0x1B03 (lifetime stats)
       → paginate 0x1B04 (kill log)
       → write 0x1B12 (time sync)
       → write 0x1B11 (config)
```

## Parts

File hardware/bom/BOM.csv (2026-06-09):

Ref | Value | Package | Qty | Description | MPN | Supplier | Est.Price(CNY)
U1 | ESP32-C3-MINI-1 | Module | 1 | MCU with BLE 5.0 | ESP32-C3-MINI-1 | Espressif | 9.00
U2 | AHT20 | DFN-6 | 1 | Temperature & Humidity Sensor | AHT20 | Aosong | 2.50
U3 | ME6211C33M5G | SOT-23-5 | 1 | LDO 3.3V 500mA | ME6211C33M5G | ME | 0.30
U4 | TP4056 | SOP-8 | 1 | Li-ion Charger IC | TP4056 | Nanjing Top Power | 0.40
U5 | DW01A | SOT-23-6 | 1 | Battery Protection IC | DW01A | Fortune Semi | 0.25
U6 | LMV358 | SOP-8 | 1 | Rail-to-Rail Op-Amp Dual | LMV358IDR | TI | 0.80
U7 | NE555 | SOP-8 | 1 | Timer/Oscillator | NE555DR | TI | 0.30
U8 | USBLC6-2SC6 | SOT-23-6L | 1 | USB ESD Protection | USBLC6-2SC6 | ST | 0.50
Q1 | AO3400 | SOT-23 | 1 | N-ch MOSFET 30V 5.7A Rds=40mΩ | AO3400A | Alpha & Omega | 0.35
Q2 | FS8205A | TSSOP-8 | 1 | Dual MOSFET for Battery Protect | FS8205A | Fortune Semi | 0.25
Q3 | 2N7002 | SOT-23 | 1 | N-ch MOSFET 60V 115mA Grid Discharge | 2N7002 | Nexperia | 0.10
D1-D6 | UF4007 | SMA | 6 | Fast Recovery Diode 1kV trr=75ns | UF4007 | General | 0.60
D7 | BAT54S | SOT-23 | 1 | Schottky Clamp Dual | BAT54S | Nexperia | 0.20
D8 | BAT43 | DO-35 | 1 | Schottky Diode Vf=0.2V Peak Detector | BAT43 | Vishay | 0.15
D9 | BZX84C3V3 | SOT-23 | 1 | 3.3V Zener Backup Clamp | BZX84C3V3 | Nexperia | 0.10
D10 | SMBJ24A | SMB | 1 | TVS 24V Flyback Protection | SMBJ24A | Littelfuse | 0.50
D11 | SS34 | SMA | 1 | Schottky 40V 3A USB VBUS Reverse Prot. | SS34 | MDD | 0.30
D12 | WS2812B | 5050 | 1 | RGB LED Addressable | WS2812B | Worldsemi | 0.30
T1 | EE13/EE16 10:200 | EE13 | 1 | Step-up Transformer 1:20 effective | Custom wound | Local | 2.00
BZ1 | Passive Piezo | 12mm | 1 | Buzzer | Generic | Local | 0.50
J1 | USB-C 16P | SMD | 1 | USB Type-C Connector | Generic 16pin | Local | 0.50
SW1 | Tactile 6x6mm | SMD | 1 | Main Button | Generic | Local | 0.10
C1-C6 | 1nF 2kV | 0805 HV | 6 | HV Multiplier Caps C0G | Generic C0G | Local | 0.60
C7 | 10uF | 0805 | 1 | LDO Output Cap | Generic X5R | Local | 0.05
C8-C11 | 100nF | 0402 | 4 | Decoupling Caps | Generic X7R | Local | 0.08
C12 | 4.7uF | 0805 | 1 | TP4056 Input Cap | Generic X5R | Local | 0.05
C13 | 1uF | 0805 | 1 | Peak Detector Hold Cap | Generic X7R | Local | 0.03
C14 | 100nF | 0402 | 1 | Battery Divider Filter Cap | Generic X7R | Local | 0.02
C15 | 1nF | 0402 | 1 | Snubber Cap (across Q1 D-S) | Generic C0G | Local | 0.01
C16 | 10uF | 0805 | 1 | HV_EN Watchdog RC Cap | Generic X5R | Local | 0.05
R1 | 0.1R 2W | 2512 | 1 | Current Sense Resistor | Generic | Local | 0.15
R2-R3 | 10K | 0402 | 2 | Battery Voltage Divider | Generic | Local | 0.02
R4 | 2K | 0402 | 1 | TP4056 Charge Current Set | Generic | Local | 0.01
R5 | 1.5K | 0402 | 1 | Anti-alias Filter R | Generic | Local | 0.01
R6 | 100K | 0402 | 1 | Peak Detector Decay R | Generic | Local | 0.01
R7 | 1K | 0402 | 1 | Series Limit R Before Clamp | Generic | Local | 0.01
R8 | 19K | 0402 | 1 | Op-Amp Feedback Rf (Gain=20) | Generic | Local | 0.01
R9 | 1K | 0402 | 1 | Op-Amp Input Rg (Gain=20) | Generic | Local | 0.01
R10 | 100R | 0402 | 1 | Snubber R (across Q1 D-S) | Generic | Local | 0.01
R11 | 100R | 0805 | 1 | Grid Discharge Resistor | Generic | Local | 0.01
R12 | 100K | 0805 | 1 | HV_EN Watchdog RC Resistor | Generic | Local | 0.01
R13 | 10K | 0402 | 1 | TP4056 TEMP Pin to VCC | Generic | Local | 0.01
R14 | 4.7K | 0402 | 1 | NE555 R_A | Generic | Local | 0.01
R15 | 10K | 0402 | 1 | NE555 R_B | Generic | Local | 0.01
R16-R25 | 1M 200V | 0805 | 10 | HV Grid Bleed Resistor Chain | Generic | Local | 0.20
R26-R30 | Assorted | 0402 | 5 | Pull-ups/bias | Generic | Local | 0.05
 |  |  |  |  |  | TOTAL | ~24.48

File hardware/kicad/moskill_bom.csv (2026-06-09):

Refs | Value | Footprint | Qty | DNP
BZ1 | Buzzer | Buzzer_Beeper:Buzzer_12x9.5RM7.6 | 1
C1 | 1nF/2kV | Capacitor_SMD:C_0805_2012Metric | 1
C2 | 1nF/2kV | Capacitor_SMD:C_0805_2012Metric | 1
C3 | 1nF/2kV | Capacitor_SMD:C_0805_2012Metric | 1
C4 | 1nF/2kV | Capacitor_SMD:C_0805_2012Metric | 1
C5 | 1nF/2kV | Capacitor_SMD:C_0805_2012Metric | 1
C6 | 1nF/2kV | Capacitor_SMD:C_0805_2012Metric | 1
C7 | 10uF | Capacitor_SMD:C_0805_2012Metric | 1
C8 | 100nF | Capacitor_SMD:C_0402_1005Metric | 1
C9 | 100nF | Capacitor_SMD:C_0402_1005Metric | 1
C10 | 10uF | Capacitor_SMD:C_0805_2012Metric | 1
C11 | 100nF | Capacitor_SMD:C_0402_1005Metric | 1
C12 | 4.7uF | Capacitor_SMD:C_0805_2012Metric | 1
C13 | 1uF | Capacitor_SMD:C_0402_1005Metric | 1
C14 | 100nF | Capacitor_SMD:C_0402_1005Metric | 1
C15 | 1nF | Capacitor_SMD:C_0402_1005Metric | 1
C16 | 10uF | Capacitor_SMD:C_0805_2012Metric | 1
C17 | 10uF | Capacitor_SMD:C_0805_2012Metric | 1
C18 | 100nF | Capacitor_SMD:C_0402_1005Metric | 1
C19 | 100nF | Capacitor_SMD:C_0402_1005Metric | 1
C20 | 100nF | Capacitor_SMD:C_0402_1005Metric | 1
C21 | 10nF | Capacitor_SMD:C_0402_1005Metric | 1
C22 | 10nF | Capacitor_SMD:C_0402_1005Metric | 1
C23 | 10nF | Capacitor_SMD:C_0402_1005Metric | 1
C24 | 100pF | Capacitor_SMD:C_0402_1005Metric | 1
D1 | UF4007 | Diode_SMD:D_SMA | 1
D2 | UF4007 | Diode_SMD:D_SMA | 1
D3 | UF4007 | Diode_SMD:D_SMA | 1
D4 | UF4007 | Diode_SMD:D_SMA | 1
D5 | UF4007 | Diode_SMD:D_SMA | 1
D6 | UF4007 | Diode_SMD:D_SMA | 1
D7 | BAT54S | Package_TO_SOT_SMD:SOT-23 | 1
D8 | BAT43 | Diode_SMD:D_SOD-323 | 1
D9 | BZX84C3V3 | Package_TO_SOT_SMD:SOT-23 | 1
D10 | SMBJ24A | Diode_SMD:D_SMB | 1
D11 | SS34 | Diode_SMD:D_SMA | 1
D12 | WS2812B | LED_SMD:LED_WS2812B_PLCC4_5.0x5.0mm_P3.2mm | 1
D13 | LED_STDBY | LED_SMD:LED_0402_1005Metric | 1
J1 | USB-C | Connector_USB:USB_C_Receptacle_XKB_U262-16XN-4BVC11 | 1
Q1 | AO3400A | Package_TO_SOT_SMD:SOT-23 | 1
Q2 | FS8205A | Package_SO:TSSOP-8_4.4x3mm_P0.65mm | 1
Q3 | 2N7002 | Package_TO_SOT_SMD:SOT-23 | 1
Q4 | 2N7002 | Package_TO_SOT_SMD:SOT-23 | 1
Q5 | 2N7002 | Package_TO_SOT_SMD:SOT-23 | 1
R1 | 0R1_2W | Resistor_SMD:R_2512_6332Metric | 1
R2 | 10K | Resistor_SMD:R_0402_1005Metric | 1
R3 | 10K | Resistor_SMD:R_0402_1005Metric | 1
R4 | 2K | Resistor_SMD:R_0402_1005Metric | 1
R5 | 1.5K | Resistor_SMD:R_0402_1005Metric | 1
R6 | 100K | Resistor_SMD:R_0402_1005Metric | 1
R7 | 1K | Resistor_SMD:R_0402_1005Metric | 1
R8 | 19K | Resistor_SMD:R_0402_1005Metric | 1
R9 | 1K | Resistor_SMD:R_0402_1005Metric | 1
R10 | 100R | Resistor_SMD:R_0402_1005Metric | 1
R11 | 100R | Resistor_SMD:R_0402_1005Metric | 1
R12 | 100K | Resistor_SMD:R_0402_1005Metric | 1
R13 | 10K | Resistor_SMD:R_0402_1005Metric | 1
R14 | 4.7K | Resistor_SMD:R_0402_1005Metric | 1
R15 | 10K | Resistor_SMD:R_0402_1005Metric | 1
R16 | 1M | Resistor_SMD:R_0805_2012Metric | 1
R17 | 1M | Resistor_SMD:R_0805_2012Metric | 1
R18 | 1M | Resistor_SMD:R_0805_2012Metric | 1
R19 | 1M | Resistor_SMD:R_0805_2012Metric | 1
R20 | 1M | Resistor_SMD:R_0805_2012Metric | 1
R21 | 1M | Resistor_SMD:R_0805_2012Metric | 1
R22 | 1M | Resistor_SMD:R_0805_2012Metric | 1
R23 | 1M | Resistor_SMD:R_0805_2012Metric | 1
R24 | 1M | Resistor_SMD:R_0805_2012Metric | 1
R25 | 1M | Resistor_SMD:R_0805_2012Metric | 1
R26 | 10K | Resistor_SMD:R_0402_1005Metric | 1
R27 | 4.7K | Resistor_SMD:R_0402_1005Metric | 1
R28 | 4.7K | Resistor_SMD:R_0402_1005Metric | 1
R29 | 100R | Resistor_SMD:R_0402_1005Metric | 1
R30 | 10K | Resistor_SMD:R_0402_1005Metric | 1
R31 | 10K | Resistor_SMD:R_0402_1005Metric | 1
R32 | 5.1K | Resistor_SMD:R_0402_1005Metric | 1
R33 | 5.1K | Resistor_SMD:R_0402_1005Metric | 1
R34 | 10K | Resistor_SMD:R_0402_1005Metric | 1
R35 | 1K | Resistor_SMD:R_0402_1005Metric | 1
R36 | 100R | Resistor_SMD:R_0402_1005Metric | 1
SW1 | Button | Button_Switch_SMD:SW_SPST_PTS645 | 1
T1 | EE13 1:20 | Inductor_SMD:L_Bourns_SRR1208_12.7x12.7mm | 1
U1A? | ESP32-C3-L | Espressif:ESP32-C3-MINI-1 | 1
U1B? | ESP32-C3-R | Espressif:ESP32-C3-MINI-1 | 1
U2 | AHT20 | Sensor_Humidity:Sensirion_DFN-4_1.5x1.5mm_P0.8mm_SHT4x_NoCentralPad | 1
U3 | ME6211C33 | Package_TO_SOT_SMD:SOT-23-5 | 1
U4 | TP4056 | Package_SO:SOIC-8_3.9x4.9mm_P1.27mm | 1
U5 | DW01A | Package_TO_SOT_SMD:SOT-23-6 | 1
U6 | LMV321/LMV358 | Package_TO_SOT_SMD:SOT-23-5 | 1
U7 | NE555 | Package_SO:SOIC-8_3.9x4.9mm_P1.27mm | 1
U8 | USBLC6-2SC6 | Package_TO_SOT_SMD:SOT-23-6 | 1

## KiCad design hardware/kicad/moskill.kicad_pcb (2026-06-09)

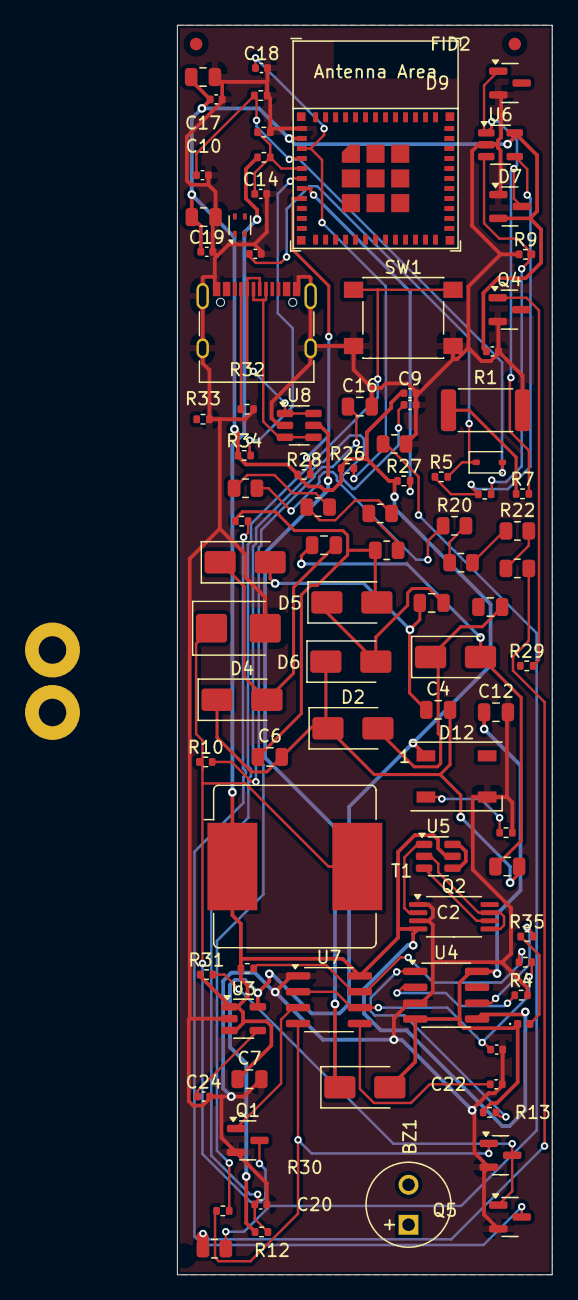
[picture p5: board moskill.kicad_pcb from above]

Board: 2 copper layers, 30.0 x 100.0 mm, 95 parts (1 on the bottom side), 58 nets.

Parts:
BZ1: Buzzer; MagneticBuzzer_Kingstate_KCG0601
C1, C2, C3, C4, C5, C6: 1nF/2kV; C_0805_2012Metric
C7, C10, C16, C17: 10uF; C_0805_2012Metric
C8, C9, C11, C14, C18, C19, C20: 100nF; C_0402_1005Metric
C12: 4.7uF; C_0805_2012Metric
C13: 1uF; C_0402_1005Metric
C15: 1nF; C_0402_1005Metric
C21, C22, C23: 10nF; C_0402_1005Metric
C24: 100pF; C_0402_1005Metric
D1, D2, D3, D4, D5, D6: UF4007; D_SMA
D7: BAT54S; SOT-23
D8: BAT43; D_SOD-323
D9: BZX84C3V3; SOT-23
D10: SMBJ24A; D_SMB
D11: SS34; D_SMA
D12: WS2812B; LED_WS2812B_PLCC4_5.0x5.0mm_P3.2mm
D13: LED_STDBY; LED_0402_1005Metric
FID1, FID2, FID3: Fiducial; Fiducial_1mm_Mask2mm
H1, H2: M2; MountingHole_2.2mm_M2_Pad
J1: USB-C; USB_C_Receptacle_XKB_U262-16XN-4BVC11
Q1: AO3400A; SOT-23
Q2: FS8205A; TSSOP-8_4.4x3mm_P0.65mm
Q3, Q4, Q5: 2N7002; SOT-23
R1: 0R1_2W; R_2512_6332Metric
R2, R3, R13, R15, R26, R30, R31, R34: 10K; R_0402_1005Metric
R4: 2K; R_0402_1005Metric
R5: 1.5K; R_0402_1005Metric
R6, R12: 100K; R_0402_1005Metric
R7, R9, R35: 1K; R_0402_1005Metric
R8: 19K; R_0402_1005Metric
R10, R11, R29, R36: 100R; R_0402_1005Metric
R14, R27, R28: 4.7K; R_0402_1005Metric
R16, R17, R18, R19, R20, R21, R22, R23, R24, R25: 1M; R_0805_2012Metric
R32, R33: 5.1K; R_0402_1005Metric
SW1: Button; SW_SPST_PTS645
T1: EE13 1:20; L_Bourns_SRR1208_12.7x12.7mm
U1A: ESP32-C3-L; ESP32-C3-MINI-1
U2: AHT20; Sensirion_DFN-4_1.5x1.5mm_P0.8mm_SHT4x_NoCentralPad
U3: ME6211C33; SOT-23-5
U4: TP4056; SOIC-8_3.9x4.9mm_P1.27mm
U5: DW01A; SOT-23-6
U6: LMV321/LMV358; SOT-23-5
U7: NE555; SOIC-8_3.9x4.9mm_P1.27mm
U8: USBLC6-2SC6; SOT-23-6

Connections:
+3V3: C8.1, C9.1, C10.1, C11.1, C17.1, C19.1, D7.2, D12.1, R26.1, R27.1, R28.1, R30.1, R34.1, U1A.2, U2.1, U3.5, U6.5
+5V_PROT: C12.1, D11.2, D13.1, R13.1, U4.4, U4.8
+BATT: C7.1, Q2.4, Q2.8, R2.1, R14.1, R31.1, T1.1, U3.1, U3.3, U4.5, U5.5, U7.8
ADC_SENSE: C13.1, D8.2, R6.1, U1A.4
BLD_0: R16.2, R17.1
BLD_1: R17.2, R18.1
BLD_2: R18.2, R19.1
BLD_3: R19.2, R20.1
BLD_4: R20.2, R21.1
BLD_5: R21.2, R22.1
BLD_6: R22.2, R23.1
BLD_7: R23.2, R24.1
BLD_8: R24.2, R25.1
BOOT: R34.2, U1A.6
BTN_IN: C20.1, R30.2, SW1.1
BUZ_GATE: Q4.1, R29.2
CC1: J1.A5, R32.1
CC2: J1.B5, R33.1
CS_SENSE: Q2.5, Q2.7, U5.2
CW_N1: C1.2, D1.1, D2.2
CW_N2: C2.1, C3.1, D1.2
CW_N3: C3.2, D3.1, D4.2
CW_N4: C4.1, C5.1, D3.2
CW_N5: C5.2, D5.1, D6.2
DISCH_DRN: Q3.3, R11.2
EN: C18.1, R26.2, U1A.3
FILT_OUT: C23.1, D8.1, R5.2
GND: C7.2, C8.2, C9.2, C10.2, C11.2, C12.2, C13.2, C14.2, C15.2, C16.2, C17.2, C18.2, C19.2, C20.2, C21.2, C22.2, C23.2, C24.2, D7.1, D9.2, D10.2, D12.3, J1.A1, J1.A12, J1.B1, J1.B12, J1.S1, Q1.2, Q2.1, Q2.3, Q3.2, Q4.2, Q5.2, R1.2, R3.2, R4.2, R6.2, R9.1, R25.2, R32.2, R33.2, R36.2, SW1.2, U1A.1, U2.3, U3.2, U4.3, U6.2, U7.1, U8.2
GND_BAT: U5.4, U5.6
HV_EN: Q5.1, R12.1, U7.4
HV_EN_INV: Q3.1, Q5.3, R31.2
HV_EN_RC: C16.1, R12.2
HV_OUT: C6.1, D5.2, R11.1, R16.1
HV_RET: R1.1, R7.1
HV_SEC_BOT: C2.2, C4.2, C6.2, D2.1, D4.1, D6.1
I2C_SCL: R28.2, U1A.8, U2.4
I2C_SDA: R27.2, U1A.7, U2.2
LDO_BP: C24.1, U3.4
LED_DOUT_RAW: D12.2, R36.1
NE555_CV: C22.1, U7.5
NE555_DIS: R14.2, R15.1, U7.7
NE555_OUT: Q1.1, U7.3
NE555_THR_TR: C21.1, R15.2, U7.2, U7.6
OC: Q2.6, U5.3
OD: Q2.2, U5.1
OPAMP_INM: R8.2, R9.2, U6.3
OPAMP_OUT: R5.1, R8.1, U6.4
PROG: R4.1, U4.2
Q1_DRAIN: D10.1, Q1.3, R10.1, T1.2
SENSE_LIM: D7.3, D9.1, R7.2, U6.1
SNUB_M: C15.1, R10.2
STDBY_LED: D13.2, R35.1
STDBY_OUT: R35.2, U4.6
TEMP_TP: R13.2, U4.1
USB_DM: J1.A7, J1.B7, U8.1, U8.6
USB_DP: J1.A6, J1.B6, U8.3, U8.4
VBAT_SENSE: C14.1, R2.2, R3.1, U1A.5
VBUS: D11.1, J1.A4, J1.A9, J1.B4, J1.B9, U8.5

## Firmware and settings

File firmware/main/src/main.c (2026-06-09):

#include <stdio.h>
#include "freertos/FreeRTOS.h"
#include "freertos/task.h"
#include "freertos/queue.h"
#include "esp_log.h"
#include "nvs_flash.h"
#include "driver/gpio.h"

#include "moskill_config.h"
#include "moskill_types.h"
#include "kill_detector.h"
#include "stats_engine.h"
#include "ble_service.h"
#include "power_mgmt.h"
#include "env_sensor.h"
#include "ui_driver.h"

static const char *TAG = "moskill";

QueueHandle_t kill_event_queue;

void app_main(void)
{
    ESP_LOGI(TAG, "MosKill v1.0.0 starting...");

    esp_err_t ret = nvs_flash_init();
    if (ret == ESP_ERR_NVS_NO_FREE_PAGES || ret == ESP_ERR_NVS_NEW_VERSION_FOUND) {
        ESP_ERROR_CHECK(nvs_flash_erase());
        ret = nvs_flash_init();
    }
    ESP_ERROR_CHECK(ret);

    kill_event_queue = xQueueCreate(16, sizeof(kill_event_t));
    assert(kill_event_queue != NULL);

    stats_engine_init();
    env_sensor_init();
    ui_driver_init();
    power_mgmt_init();
    kill_detector_init(kill_event_queue);
    ble_service_init();

    xTaskCreate(kill_detector_task, "kill_det", 4096, NULL, 5, NULL);
    xTaskCreate(stats_engine_task, "stats", 8192, NULL, 4, NULL);
    xTaskCreate(ble_service_task, "ble", 6144, NULL, 3, NULL);
    xTaskCreate(env_sensor_task, "env", 2048, NULL, 2, NULL);
    xTaskCreate(ui_driver_task, "ui", 2048, NULL, 2, NULL);
    xTaskCreate(power_mgmt_task, "power", 2048, NULL, 1, NULL);

    ESP_LOGI(TAG, "All tasks launched. Entering idle.");
}

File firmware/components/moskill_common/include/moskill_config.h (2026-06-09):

#pragma once

// -- Hardware Pins --
#define PIN_CURRENT_SENSE   0   // ADC channel 0
#define PIN_BATTERY_ADC     1   // ADC channel 1
#define PIN_I2C_SDA         4
#define PIN_I2C_SCL         5
#define PIN_HV_ENABLE       6
#define PIN_LED_STATUS      7
#define PIN_BUZZER          8
#define PIN_BUTTON          9
#define PIN_CHARGE_STATUS   10

// -- ADC --
#define ADC_SAMPLE_RATE_HZ  1000
#define ADC_ATTEN           3       // ADC_ATTEN_DB_11
#define ADC_WIDTH           4       // ADC_BITWIDTH_12 (ESP-IDF v5.x)
#define ADC_MAX_VALUE       4095

// -- Kill Detection Thresholds --
#define KILL_THRESHOLD_LOW      200
#define KILL_THRESHOLD_HIGH     3800
#define KILL_MIN_SUSTAIN_MS     5
#define KILL_MAX_DURATION_MS    500
#define KILL_COOLDOWN_MS        200
#define KILL_RISE_MAX_MS        2
#define KILL_DECAY_MAX_MS       100

// -- Kill Classification (ADC peak ranges) --
#define KILL_CLASS_S_MAX    800
#define KILL_CLASS_M_MAX    2000
#define KILL_CLASS_L_MAX    3200

// -- Sensitivity Presets --
#define SENSITIVITY_LOW     300
#define SENSITIVITY_MED     200
#define SENSITIVITY_HIGH    120

// -- Battery --
#define BAT_VOLTAGE_DIVIDER_RATIO   2.0f
#define BAT_FULL_MV         4200
#define BAT_EMPTY_MV        3000
#define BAT_LOW_THRESHOLD   15

// -- Environment Sensor --
#define ENV_SAMPLE_INTERVAL_MS  30000
#define AHT20_I2C_ADDR      0x38

// -- BLE --
#define BLE_DEVICE_NAME_PREFIX  "MosKill"
#define BLE_ADV_FAST_MS     200
#define BLE_ADV_SLOW_MS     1000
#define BLE_ADV_SLOW_AFTER_MS   30000
#define BLE_MAX_BONDS       4
#define BLE_MTU_SIZE        247

// -- Stats --
#define KILL_LOG_MAX_ENTRIES     256
#define KILL_LOG_PAGE_SIZE       10
#define KILL_LOG_SHARD_SIZE      64
#define KILL_LOG_NUM_SHARDS      (KILL_LOG_MAX_ENTRIES / KILL_LOG_SHARD_SIZE)
#define STREAK_WINDOW_MS         10000
#define NVS_NAMESPACE            "moskill"

// -- UI --
#define LED_KILL_FLASH_MS        200
#define BUZZER_KILL_FREQ_HZ      2000
#define BUZZER_KILL_DURATION_MS   50
#define BUZZER_LOW_BAT_FREQ_HZ   1000

// -- Power --
#define DEEP_SLEEP_TIMEOUT_MS    300000  // 5 min no activity
#define LIGHT_SLEEP_TIMEOUT_MS   30000   // 30s no activity

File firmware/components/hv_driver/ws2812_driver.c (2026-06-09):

#include "ws2812_driver.h"
#include "driver/rmt_tx.h"
#include "esp_log.h"
#include "freertos/FreeRTOS.h"
#include "freertos/task.h"
#include <string.h>
#include <math.h>

static const char *TAG = "ws2812";

#define WS2812_T0H_NS  350
#define WS2812_T0L_NS  900
#define WS2812_T1H_NS  900
#define WS2812_T1L_NS  350
#define WS2812_RESET_NS 50000

#define MAX_LEDS 8

static rmt_channel_handle_t s_channel = NULL;
static rmt_encoder_handle_t s_encoder = NULL;
static ws2812_color_t s_leds[MAX_LEDS];
static int s_num_leds = 0;
static uint8_t s_brightness = 255;

typedef struct {
    rmt_encoder_t base;
    rmt_encoder_t *bytes_encoder;
    rmt_encoder_t *copy_encoder;
    int state;
    rmt_symbol_word_t reset_code;
} ws2812_encoder_t;

static size_t ws2812_encode(rmt_encoder_t *encoder, rmt_channel_handle_t channel,
                             const void *primary_data, size_t data_size,
                             rmt_encode_state_t *ret_state)
{
    ws2812_encoder_t *ws_enc = __containerof(encoder, ws2812_encoder_t, base);
    rmt_encode_state_t session_state = RMT_ENCODING_RESET;
    size_t encoded_symbols = 0;

    switch (ws_enc->state) {
    case 0:
        encoded_symbols += ws_enc->bytes_encoder->encode(ws_enc->bytes_encoder, channel,
                                                          primary_data, data_size, &session_state);
        if (session_state & RMT_ENCODING_COMPLETE) {
            ws_enc->state = 1;
        }
        if (session_state & RMT_ENCODING_MEM_FULL) {
            *ret_state = (rmt_encode_state_t)RMT_ENCODING_MEM_FULL;
            return encoded_symbols;
        }
        // fall through
    case 1:
        encoded_symbols += ws_enc->copy_encoder->encode(ws_enc->copy_encoder, channel,
                                                         &ws_enc->reset_code, sizeof(ws_enc->reset_code),
                                                         &session_state);
        if (session_state & RMT_ENCODING_COMPLETE) {
            ws_enc->state = RMT_ENCODING_RESET;
            *ret_state = (rmt_encode_state_t)RMT_ENCODING_COMPLETE;
        }
        if (session_state & RMT_ENCODING_MEM_FULL) {
            *ret_state = (rmt_encode_state_t)RMT_ENCODING_MEM_FULL;
        }
        break;
    }
    return encoded_symbols;
}

static esp_err_t ws2812_del(rmt_encoder_t *encoder)
{
    ws2812_encoder_t *ws_enc = __containerof(encoder, ws2812_encoder_t, base);
    rmt_del_encoder(ws_enc->bytes_encoder);
    rmt_del_encoder(ws_enc->copy_encoder);
    free(ws_enc);
    return ESP_OK;
}

static esp_err_t ws2812_reset(rmt_encoder_t *encoder)
{
    ws2812_encoder_t *ws_enc = __containerof(encoder, ws2812_encoder_t, base);
    rmt_encoder_reset(ws_enc->bytes_encoder);
    rmt_encoder_reset(ws_enc->copy_encoder);
    ws_enc->state = RMT_ENCODING_RESET;
    return ESP_OK;
}

static esp_err_t create_encoder(rmt_encoder_handle_t *ret_encoder, uint32_t resolution)
{
    ws2812_encoder_t *ws_enc = calloc(1, sizeof(ws2812_encoder_t));
    if (!ws_enc) return ESP_ERR_NO_MEM;

    ws_enc->base.encode = ws2812_encode;
    ws_enc->base.del = ws2812_del;
    ws_enc->base.reset = ws2812_reset;

    rmt_bytes_encoder_config_t bytes_cfg = {
        .bit0 = {
            .duration0 = WS2812_T0H_NS * resolution / 1000000000,
            .level0 = 1,
            .duration1 = WS2812_T0L_NS * resolution / 1000000000,
            .level1 = 0,
        },
        .bit1 = {
            .duration0 = WS2812_T1H_NS * resolution / 1000000000,
            .level0 = 1,
            .duration1 = WS2812_T1L_NS * resolution / 1000000000,
            .level1 = 0,
        },
        .flags.msb_first = 1,
    };
    ESP_ERROR_CHECK(rmt_new_bytes_encoder(&bytes_cfg, &ws_enc->bytes_encoder));

    rmt_copy_encoder_config_t copy_cfg = {};
    ESP_ERROR_CHECK(rmt_new_copy_encoder(&copy_cfg, &ws_enc->copy_encoder));

    uint32_t reset_ticks = WS2812_RESET_NS * resolution / 1000000000;
    ws_enc->reset_code = (rmt_symbol_word_t){
        .duration0 = reset_ticks / 2,
        .level0 = 0,
        .duration1 = reset_ticks / 2,
        .level1 = 0,
    };

    *ret_encoder = &ws_enc->base;
    return ESP_OK;
}

void ws2812_init(int gpio_num, int num_leds)
{
    if (num_leds > MAX_LEDS) num_leds = MAX_LEDS;
    s_num_leds = num_leds;
    memset(s_leds, 0, sizeof(s_leds));

    uint32_t resolution = 10000000; // 10MHz → 100ns per tick

    rmt_tx_channel_config_t tx_cfg = {
        .gpio_num = gpio_num,
        .clk_src = RMT_CLK_SRC_DEFAULT,
        .resolution_hz = resolution,
        .mem_block_symbols = 64,
        .trans_queue_depth = 4,
    };
    ESP_ERROR_CHECK(rmt_new_tx_channel(&tx_cfg, &s_channel));
    ESP_ERROR_CHECK(create_encoder(&s_encoder, resolution));
    ESP_ERROR_CHECK(rmt_enable(s_channel));

    ESP_LOGI(TAG, "WS2812 initialized: gpio=%d leds=%d", gpio_num, num_leds);
}

void ws2812_set(int index, ws2812_color_t color)
{
    if (index < 0 || index >= s_num_leds) return;
    s_leds[index].r = (uint8_t)((uint16_t)color.r * s_brightness / 255);
    s_leds[index].g = (uint8_t)((uint16_t)color.g * s_brightness / 255);
    s_leds[index].b = (uint8_t)((uint16_t)color.b * s_brightness / 255);
}

void ws2812_show(void)
{
    // WS2812B expects GRB order
    uint8_t buf[MAX_LEDS * 3];
    for (int i = 0; i < s_num_leds; i++) {
        buf[i * 3 + 0] = s_leds[i].g;
        buf[i * 3 + 1] = s_leds[i].r;
        buf[i * 3 + 2] = s_leds[i].b;
    }

    rmt_transmit_config_t tx_cfg = { .loop_count = 0 };
    rmt_transmit(s_channel, s_encoder, buf, s_num_leds * 3, &tx_cfg);
    rmt_tx_wait_all_done(s_channel, pdMS_TO_TICKS(100));
}

void ws2812_clear(void)
{
    memset(s_leds, 0, sizeof(s_leds));
    ws2812_show();
}

void ws2812_breathe(ws2812_color_t color, int period_ms, int step_ms)
{
    int steps = period_ms / step_ms;
    for (int i = 0; i < steps; i++) {
        float phase = (float)i / steps * 2.0f * 3.14159f;
        float brightness = (sinf(phase) + 1.0f) / 2.0f;
        ws2812_color_t c = {
            .r = (uint8_t)(color.r * brightness),
            .g = (uint8_t)(color.g * brightness),
            .b = (uint8_t)(color.b * brightness),
        };
        ws2812_set(0, c);
        ws2812_show();
        vTaskDelay(pdMS_TO_TICKS(step_ms));
    }
}
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

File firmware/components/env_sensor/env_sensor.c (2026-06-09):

#include "env_sensor.h"
#include "moskill_config.h"
#include "ble_service.h"

#include "freertos/FreeRTOS.h"
#include "freertos/task.h"
#include "driver/i2c.h"
#include "esp_log.h"

static const char *TAG = "env";

static portMUX_TYPE s_env_spinlock = portMUX_INITIALIZER_UNLOCKED;
static env_reading_t s_latest = { .valid = false };
static i2c_port_t s_i2c_port = I2C_NUM_0;

static esp_err_t i2c_init(void)
{
    i2c_config_t conf = {
        .mode = I2C_MODE_MASTER,
        .sda_io_num = PIN_I2C_SDA,
        .scl_io_num = PIN_I2C_SCL,
        .sda_pullup_en = GPIO_PULLUP_ENABLE,
        .scl_pullup_en = GPIO_PULLUP_ENABLE,
        .master.clk_speed = 100000,
    };
    esp_err_t err = i2c_param_config(s_i2c_port, &conf);
    if (err != ESP_OK) return err;
    return i2c_driver_install(s_i2c_port, I2C_MODE_MASTER, 0, 0, 0);
}

static esp_err_t aht20_trigger_measurement(void)
{
    uint8_t cmd[] = { 0xAC, 0x33, 0x00 };
    return i2c_master_write_to_device(s_i2c_port, AHT20_I2C_ADDR, cmd, sizeof(cmd), pdMS_TO_TICKS(100));
}

static esp_err_t aht20_read(float *temperature, float *humidity)
{
    uint8_t data[7];
    esp_err_t err = i2c_master_read_from_device(s_i2c_port, AHT20_I2C_ADDR, data, sizeof(data), pdMS_TO_TICKS(100));
    if (err != ESP_OK) return err;

    if (data[0] & 0x80) return ESP_ERR_NOT_FINISHED; // busy

    uint32_t raw_humi = ((uint32_t)data[1] << 12) | ((uint32_t)data[2] << 4) | (data[3] >> 4);
    uint32_t raw_temp = (((uint32_t)data[3] & 0x0F) << 16) | ((uint32_t)data[4] << 8) | data[5];

    *humidity = (float)raw_humi / 1048576.0f * 100.0f;
    *temperature = (float)raw_temp / 1048576.0f * 200.0f - 50.0f;

    return ESP_OK;
}

void env_sensor_init(void)
{
    esp_err_t err = i2c_init();
    if (err != ESP_OK) {
        ESP_LOGE(TAG, "I2C init failed: %s", esp_err_to_name(err));
        return;
    }

    // AHT20 soft reset
    uint8_t reset_cmd = 0xBA;
    i2c_master_write_to_device(s_i2c_port, AHT20_I2C_ADDR, &reset_cmd, 1, pdMS_TO_TICKS(100));
    vTaskDelay(pdMS_TO_TICKS(20));

    ESP_LOGI(TAG, "AHT20 initialized");
}

void env_sensor_task(void *pvParameters)
{
    while (1) {
        esp_err_t err = aht20_trigger_measurement();
        if (err == ESP_OK) {
            vTaskDelay(pdMS_TO_TICKS(80)); // AHT20 measurement time

            float temp, humi;
            err = aht20_read(&temp, &humi);
            if (err == ESP_OK) {
                portENTER_CRITICAL(&s_env_spinlock);
                s_latest.temperature = temp;
                s_latest.humidity = humi;
                s_latest.valid = true;
                portEXIT_CRITICAL(&s_env_spinlock);

                ble_notify_environment((int16_t)(temp * 10), (uint16_t)(humi * 10));

                ESP_LOGD(TAG, "Temp=%.1f°C Humi=%.1f%%", temp, humi);
            }
        }

        vTaskDelay(pdMS_TO_TICKS(ENV_SAMPLE_INTERVAL_MS));
    }
}

env_reading_t env_sensor_get_latest(void)
{
    portENTER_CRITICAL(&s_env_spinlock);
    env_reading_t copy = s_latest;
    portEXIT_CRITICAL(&s_env_spinlock);
    return copy;
}

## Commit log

2026-06-09 feat: MosKill smart mosquito swatter - full product release v1.0.0
    Complete AI-automated hardware product:
    - ESP32-C3 firmware (ESP-IDF v5.4, FreeRTOS, BLE 5.0 GATT)
    - KiCad 9 PCB (30x100mm, 91 components, Gerber ready for JLCPCB)
    - UniApp cross-platform app (Vue 3, 7 pages, SVG icons, i18n zh/en, dev mode)
    - HV boost circuit (NE555 + EE13 transformer, 3-stage Cockcroft-Walton ~2000V)
    - Kill detection (current pulse sensing, 4-class classification S/M/L/XL)
    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
    [BOM.csv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]
2026-06-09 fix: include Espressif KiCad library files (was tracked as empty submodule)
    107 files: symbols, footprints, 3D models for ESP32-C3-MINI-1
2026-06-09 docs: overhaul README with images, architecture diagram, and updated specs
    - Brand logo SVG centered at top
    - System architecture SVG diagram (HV circuit, MCU, peripherals, app)
    - PCB render images (3D + flat, top + bottom)
    - Badge bar (ESP32-C3, BLE 5.0, KiCad 9, UniApp, HV, BOM cost)
    - Updated specs: KiCad 9, 30x100mm, EE13, AO3400, 128-bit UUIDs
    - Added UniApp build section and dev mode instructions
    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
2026-06-09 fix(pcb): net class differentiation, power/HV trace widening, fiducials, GND pour
    Layout review rework (3.3/10 → improved):
    - Net classes: HV (0.25mm/0.4mm clearance), Power (0.3mm/0.25mm),
    Analog (0.2mm/0.3mm), Signal (0.2mm/0.2mm default)
    - Trace distribution: 45% signal 0.2mm, 11% HV 0.25mm, 42% power 0.3mm
    (was 93% uniform 0.2mm)
    - 3 fiducials (FID1/FID2/FID3) for SMT pick-and-place
    - Dual GND copper pour (F.Cu 1455mm² + B.Cu 1273mm²)
    - New Gerber export for JLCPCB
    Known remaining (8 unconnected, 19 other):
    - AHT20 (U2) 3 pins unroutable by FreeRouter (tight 1.5mm DFN keepout)
    - USB-C VBUS/CC2 partial connectivity (pad pitch < net class clearance)
    - Q2 +BATT gap (TSSOP pitch vs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
    [moskill-B_Courtyard.gbr, moskill-B_Cu.gbl, moskill-B_Fab.gbr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]
2026-06-09 docs: update PCB render images after layout rework
    High-quality KiCad 9 ray-traced renders (1200x3600, high quality):
    - 3D top/bottom with perspective
    - Flat top/bottom orthographic
    Reflects net class widening, fiducials, and re-routed traces.
2026-06-09 fix(pcb): fix 3D model paths KICAD6/7→KICAD9, .wrl→.step — renders now show components
    [moskill.kicad_pcb]
2026-06-09 fix(pcb): resolve all 90 missing 3D models for proper rendering
    - ESP32-C3-MINI-1 → ESP32-C3-WROOM-02 (closest KiCad 9 match)
    - USB-C XKB → GCT USB4085 (generic USB-C receptacle)
    - SW_SPST_PTS645 → PTS645Sx43SMTR92 (exact match with suffix)
    - EE13 transformer → Bourns SRP6060FA (inductor placeholder)
    - AHT20 → HDC2080 (DFN humidity sensor placeholder)
    All 90 model paths now resolve to existing .step files.
    [moskill.kicad_pcb]
2026-06-09 fix(3d): use exact ESP32-C3-MINI-1 STEP from Espressif lib, remove mismatched USB-C/transformer/AHT20 placeholders
    [moskill.kicad_pcb]
2026-06-09 fix(3d): correct ESP32-C3-MINI-1 model alignment, clean orphaned tags
    [kibot_render.yaml]
